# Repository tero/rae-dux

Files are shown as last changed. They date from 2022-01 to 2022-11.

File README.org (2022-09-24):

* rae-dux
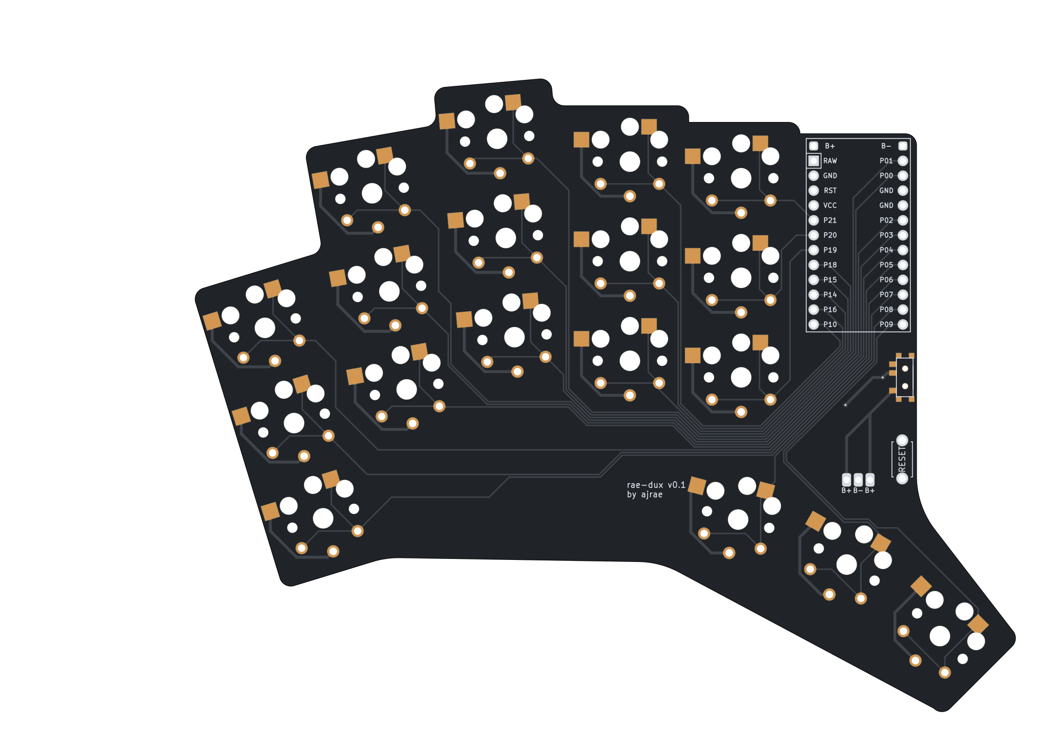
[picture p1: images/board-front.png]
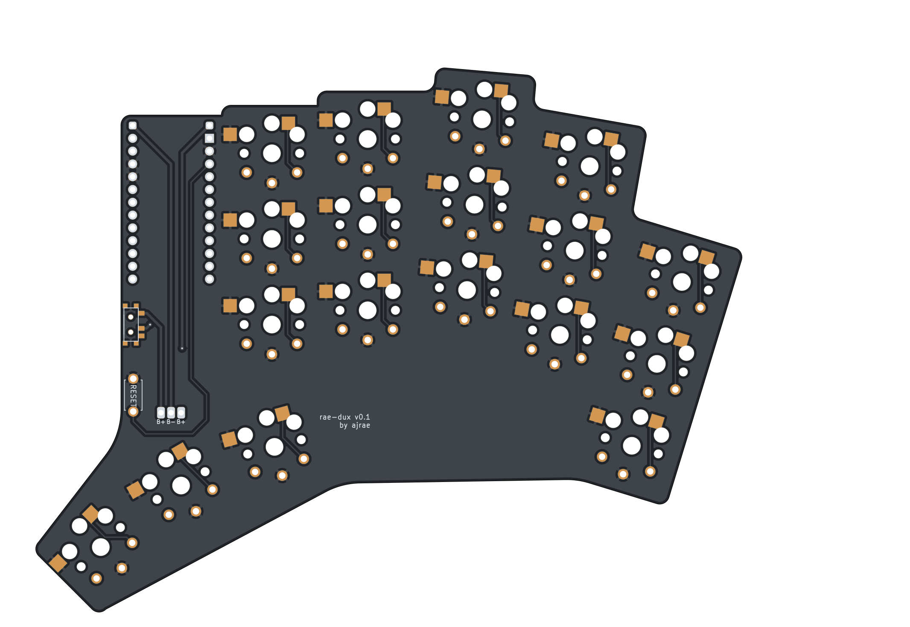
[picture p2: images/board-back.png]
|  |  |

The rae-dux is a 36-key (diodeless!), wireless keyboard inspired by the [[https://github.com/tapioki/cephalopoda/tree/main/Architeuthis%20dux][Architeuthis Dux]].
This project used to use the [[https://github.com/soundmonster/samoklava][samoklava workflow]], however the auto-router had
troubles with the splay, currently I just use the image generating parts of the
samoklava workflow.

*This has now been printed and is working perfectly with ZMK!*
The ZMK shield can be found [[https://github.com/andrewjrae/zmk-config/tree/development/config/boards/shields/rae_dux][here]], as far as I can tell small custom projects
like this aren't to be merged into ZMK main, so you'll have to emulate what I'm
doing in my =zmk-config= [[https://github.com/andrewjrae/zmk-config/tree/development/config][here]].

** Build Guide
The wonderful @tzcl created a [[https://www.tzcl.me/blog/rae-dux][build guide]] for the rae-dux, so if you are curious
about building the board, but don't have experience with this sort of thing go
check it out!

** Important Notes
- *Wireless only*, the 36-key diodeless approach uses the P0 pin which is usually dedicated to TRRS
- Since I ended up largely ditching the samoklava workflow, *the actions page with gerbers is out of date and no longer relevant**
- Their is only one MCU footprint, so *one controller has to be flipped* (I assume
   if you can get this printed you can figure out the correct orientation)
- The [[./rae-dux.yaml][rae-dux.yaml]] file relies on [[https://github.com/andrewjrae/ergogen/tree/rae-dux][my fork of ergogen]] which naturally relies on
  [[https://github.com/soundmonster/ergogen/tree/samoklava][soundmonster's fork of ergogen]], and a simple JST battery footprint inspired by
  [[https://github.com/benvallack][@benvallack]].
- If you want to skip out on the switch, there is no jumper to use the JST
  connector, so you'll have to bodge a wire somewhere, or try shorting the
  switch footprint.
- Kicad files are 6.0, so unfortunately not backwards compatible.

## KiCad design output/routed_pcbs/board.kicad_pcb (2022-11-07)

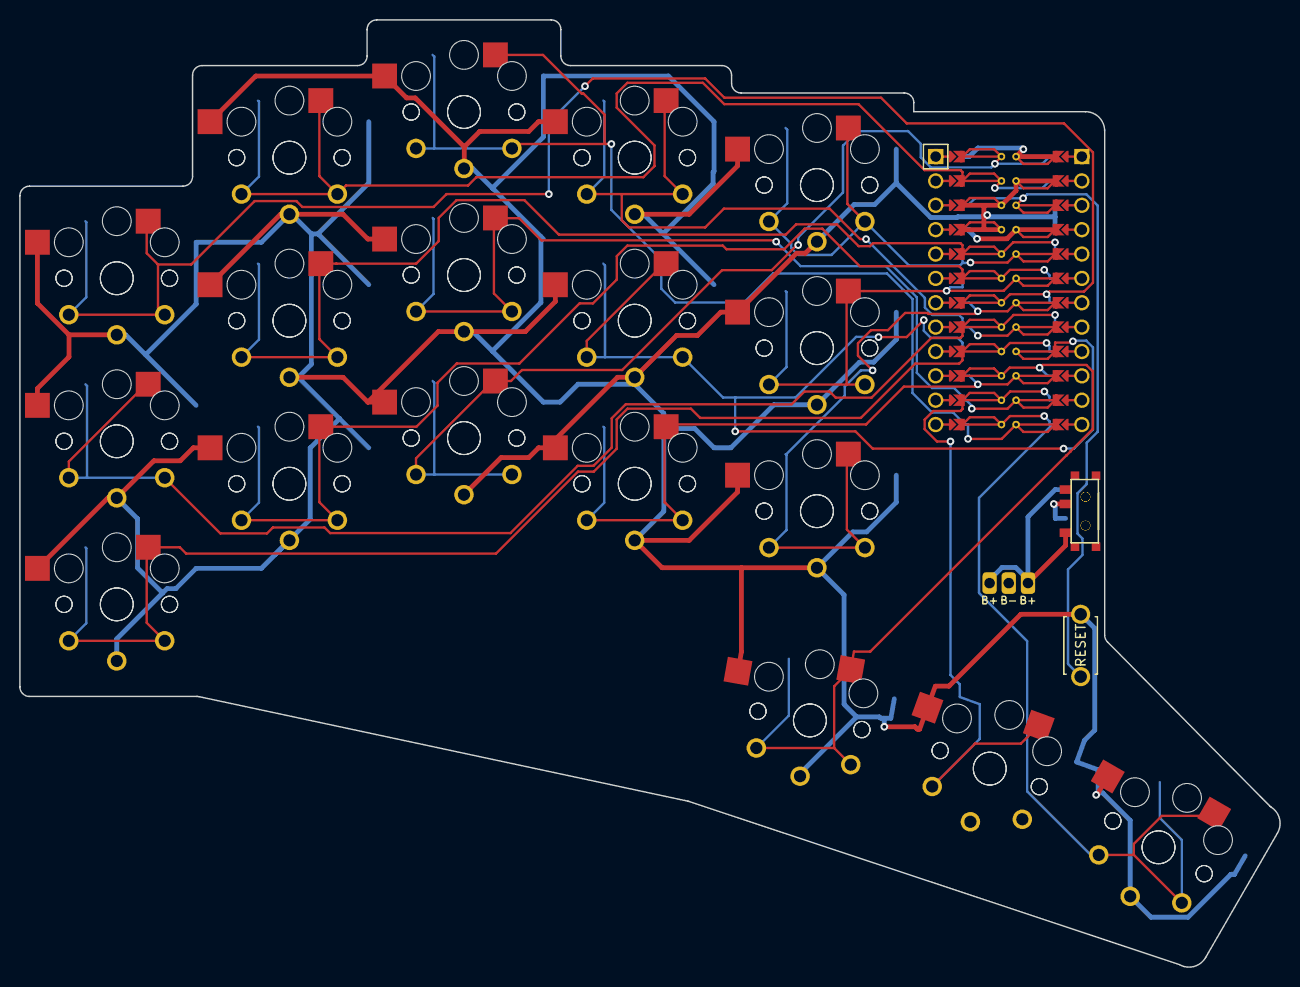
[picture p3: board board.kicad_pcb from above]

Board: 2 copper layers, 131.4 x 98.8 mm, 41 parts (0 on the bottom side), 22 nets.

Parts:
B1: ResetSW
MCU1: ProMicro
PAD1: bat
S1, S2, S3, S4, S5, S6, S7, S8, S9, S10, S11, S12, S13, S14, S15, S16, S17, S18, S19, S20, S21, S22, S23, S24, S25, S26, S27, S28, S29, S30, S31, S32, S33, S34, S35, S36: PG1350
T1, T2: SPDT_C128955

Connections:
Bplus: T1.2, T2.2
Braw: PAD1.1, T1.1, T2.1
GND: B1.2, MCU1.2, MCU1.21, MCU1.22, S1.2, S2.2, S3.2, S4.2, S5.2, S6.2, S7.2, S8.2, S9.2, S10.2, S11.2, S12.2, S13.2, S14.2, S15.2, S16.2, S17.2, S18.2, S19.2, S20.2, S21.2, S22.2, S23.2, S24.2, S25.2, S26.2, S27.2, S28.2, S29.2, S30.2, S31.2, S32.2, S33.2, S34.2, S35.2, S36.2
P0: MCU1.23, S11.1, S12.1
P1: MCU1.24, S13.1, S14.1
P2: MCU1.20, S9.1, S10.1
P3: MCU1.19, S7.1, S8.1
P4: MCU1.18, S5.1, S6.1
P5: MCU1.17, S3.1, S4.1
P6: MCU1.16, S1.1, S2.1
P7: MCU1.15, S31.1, S32.1
P8: MCU1.14, S33.1, S34.1
P9: MCU1.13, S35.1, S36.1
P10: MCU1.12, S17.1, S18.1
P14: MCU1.10, S19.1, S20.1
P15: MCU1.9, S21.1, S22.1
P16: MCU1.11, S15.1, S16.1
P18: MCU1.8, S23.1, S24.1
P19: MCU1.7, S25.1, S26.1
P20: MCU1.6, S27.1, S28.1
P21: MCU1.5, S29.1, S30.1
RST: B1.1, MCU1.3

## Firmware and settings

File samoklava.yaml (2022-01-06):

units:
  kx: cx
  ky: cy
  px: 2
  py: 2
points:
  key:
    footprints:
      choc_hotswap:
        type: choc
        params:
          hotswap: true
          reverse: true
          keycaps: true
        nets:
          # from: P1
          # to: P2
          from: =colrow
          to: =column_net
      diode:
        type: diode
        nets:
          # from: P3
          # to: P4
          from: =colrow
          to: =row_net
        anchor:
          shift: [0, -5]
  zones:
    matrix:
      # anchor:
      #   rotate: 5
      key.padding: ky
      columns:
        pinky:
          spread: 18
          rotate: 20
          origin: [0, -ky]
          key:
            bind: [0.1, 0.5 kx, 0.1, 0.1]
            column_net: P20
        ring:
          spread: 18
          stagger: 2 ky /3
          rotate: -10
          origin: [0, -ky]
          key:
            bind: [0.1, 0.5 kx, 0.1, 0.1]
            column_net: P19
        middle:
          spread: 18
          stagger: ky/3
          rotate: -5
          origin: [0, -ky]
          key:
            bind: [0.1, 0.1, 0.5 kx, 0.1]
            shift: [0.2, 0]
            column_net: P18
        index:
          spread: 18
          stagger: -ky/3
          rotate: -5
          origin: [0, -ky]
          key:
            bind: [0.1, 0.1, 0.5 kx, 0.5 kx]
            column_net: P15
        inner:
          spread: 19
          stagger: -ky/6
          origin: [0, -ky]
          key:
            bind: [0.1, 0.1, 0.1, 0.5 kx]
            column_net: P14
      rows:
        bottom:
          row_net: P6
        home:
          row_net: P5
        top:
          row_net: P4
    thumbfan:
      anchor:
        ref: matrix_inner_bottom
        shift: [-1.10 kx, -1.0 ky]
      columns:
        near:
          spread: kx
          rotate: -15
          origin: [-1.5 kx, -0.5 ky]
          key:
            column_net: P18
        home:
          spread: kx
          rotate: -15
          origin: [-0.5 kx, -0.5 ky]
          key:
            column_net: P15
        far:
          spread: kx
          rotate: -15
          origin: [-0.5 kx, -0.5 ky]
          key:
            column_net: P14
      rows:
        thumb:
          row_net: P7
outlines:
  exports:
    raw:
      - type: keys
        side: left
        size: [kx + px, ky + py]
        corner: px
    thumbfan_glue:
      - type: polygon
        points:
          - ref: matrix_inner_home
          - ref: thumbfan_far_thumb
            shift: [0.5 kx - 0.5px, 0.5 ky + 0.5 py]
          - ref: thumbfan_far_thumb
            shift: [0.5 kx - 0.5px, -0.5 ky - 0.5 py]
          - ref: thumbfan_near_thumb
            shift: [-0.5 kx - px, -0.5 ky - py]
          - ref: matrix_pinky_bottom
            shift: [0.5 kx - 0.5 py, -0.5 ky - 0.5 py]
          - ref: matrix_pinky_home
          - ref: matrix_inner_bottom
            shift: [0.5 kx + 0.5px, -0.5 ky + 0.5 py]
    controller_area:
      main:
        type: rectangle
        anchor:
          ref:
            - matrix_inner_top
          shift: [0 kx, -4.05 ky]
        size: [32, 76.5]
        corner: px
    base_outline:
      main:
        type: outline
        name: raw
        fillet: 2
      thumbfan_glue:
        type: outline
        name: thumbfan_glue
        operation: add
      controller_area:
        type: outline
        name: controller_area
        operation: add
    pcb:
      - type: outline
        name: base_outline
        fillet: 15
pcbs:
  board:
    outlines:
      edge:
        outline: pcb
        layer: Edge.Cuts
        # TODO there's a way to add stuff to the silkscreen layer
    footprints:
      mcu_l:
        type: promicro
        params:
          orientation: up
          batteryPins: true
        anchor:
          ref:
            - matrix_inner_top
          shift: [20, -11]
          rotate: 270
      mcu_r:
        type: promicro
        params:
          orientation: down
          batteryPins: true
        anchor:
          ref:
            - matrix_inner_top
          shift: [22.5, -12.25]
          rotate: 270
      pad_plus:
        type: pad
        anchor:
          ref:
            - matrix_inner_top
          shift: [23, -18]
          rotate: 0
        params:
          front: true
          back: true
          width: 1.5
          height: 1.5
          text: "B+"
        nets:
          net: Braw
      pad_minus:
        type: pad
        anchor:
          ref:
            - matrix_inner_top
          shift: [23, -15]
          rotate: 0
        params:
          front: true
          back: true
          width: 1.5
          height: 1.5
          text: "B-"
        nets:
          net: Bminus
      trrs_l:
        type: trrs
        anchor:
          ref:
            - matrix_inner_bottom
          shift: [32, -15]
          rotate: 270
        params:
          reverse: false
          symmetric: false
        # The naming of the nets on this footprint is different from the Corne schematics.
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

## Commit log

2022-01-05 Part way done, auto-routing currently isn't completing.
2022-01-06 Fixing autorouting by ensuring the MCU footprint isn't rotated.
    [samoklava.yaml]
2022-01-07 Renaming to rae-dux and fixing build flows.
2022-01-16 Starting to move towards a diodeless solution option, no more autorouting :(
2022-01-16 Adding diodeless build, requires routing.
    [board.dsn, board.kicad_pcb]
2022-01-16 Turns out autoroute works! It ain't pretty though.
    [board.dsn, board.kicad_pcb]
2022-01-16 Revert "Turns out autoroute works! It ain't pretty though." - I lied...
    This reverts commit cc5cec8c6c869663a139bc6d900cc8c8e3186058.
    [board.dsn, board.kicad_pcb]
2022-01-16 Added routed board, but the switch isn't actually functional... unless you solder directly to it.
    [board-routed.kicad_pcb]
2022-01-16 forgot to add board routed pro file
2022-01-17 Adding new style for pcbdraw
2022-01-17 Adding battery footprint, and pointing to my new ergogen fork.
    Still require routing.
    [board.kicad_pcb]
2022-01-17 Routed new design with battery connectors.
    [board-routed.kicad_pcb, board.kicad_pcb]
2022-01-17 Cleaning up board a little.
    [board-routed.kicad_pcb]
2022-01-18 Cleaning up the board even more.
    [board-routed.kicad_pcb]
2022-01-21 Increasing pinky stagger and fixing battery footprint to actually work with JST PH (fixed upstream in ergogen fork).
    [board-routed.kicad_pcb, board.dsn, board.kicad_pcb]
2022-01-21 Finished routing the latest revision.
    [board-routed.kicad_pcb]
2022-03-27 Adding gerber and updating readme.
2022-04-02 Fixing errors.
    [board-routed.kicad_pcb]
2022-11-07 add latest output
    [board-B_Cu.gbr, board-B_Mask.gbr, board-B_Paste.gbr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]
2022-11-07 update rae-dux.yaml with promicro_pretty and slight changes to pin mapping
